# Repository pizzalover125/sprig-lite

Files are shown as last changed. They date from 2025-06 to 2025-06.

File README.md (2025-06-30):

# sprig-lite
A miniature version of the Sprig game console. Featuring the smallest, Arduino-compatible DIP processor and 3 push buttons!

## Images:







## BOM 
NOTE: I am not using AliExpress because they are super unreliable and misdelivered my old package. Fourtanetly, I found it at my neighbor's house. They also just mark it as delivered when it is out for delivery. Also tariffs. 
* 5x EG1218 Slide Switch
* 2x Attiny85 w/ Socket
* 40x 1k Resistors
* 2x i2c 0.96" OLED
* 1x Keystone 2462 Battery Holder
* 1x Arduino Uno R3 (to program the board)
  
 

$57.14 w/ tax + shipping

* 1x Foam Tape
* Misc Screws

$15.00 from Home Depot w/ tax

* 5x JLC PCB ($15.55)
* Breadboard Wires (FREE)
* 3mm LEDs (FREE)
* 6mm Buttons (FREE)

**Total: $87.69**

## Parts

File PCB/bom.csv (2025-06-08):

Designator | Footprint | Quantity | Value | LCSC Part #
BT1 | BatteryHolder_Keystone_2462_2xAA | 1 | Battery
BUTTON1, BUTTON2, BUTTON3 | SW_PUSH_6mm_H4.3mm | 3 | SW_Push
D1 | LED_D3.0mm | 1 | LED
OLED1 | MODULE_DM-OLED096-636 | 1 | DM-OLED096-636
POWERSWITCH1 | SW_EG1218 | 1 | SW_Wuerth_450301014042
R1, R2, R3, R4 | R_Axial_DIN0207_L6.3mm_D2.5mm_P7.62mm_Horizontal | 4 | 1K
U1 | DIP-8_W7.62mm | 1 | ATtiny85

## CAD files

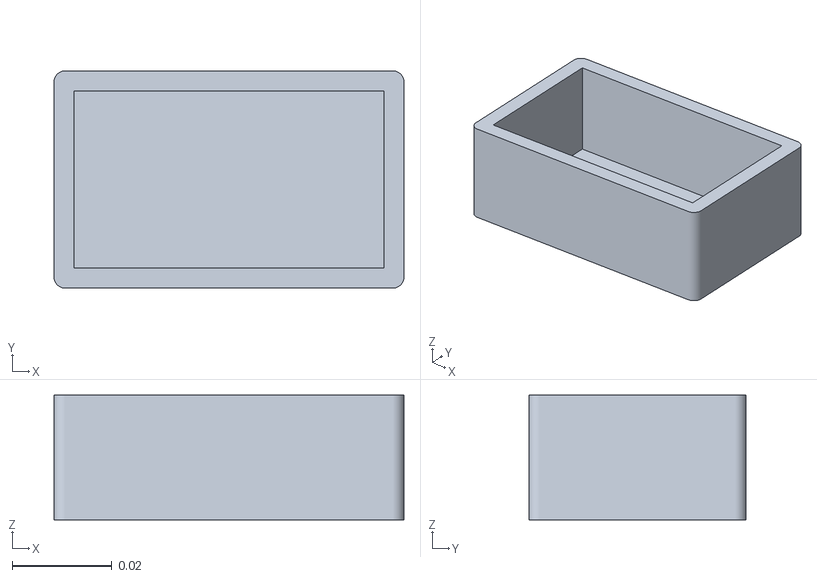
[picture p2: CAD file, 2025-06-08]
CAD/body.stl
0.0701 x 0.0435 x 0.025

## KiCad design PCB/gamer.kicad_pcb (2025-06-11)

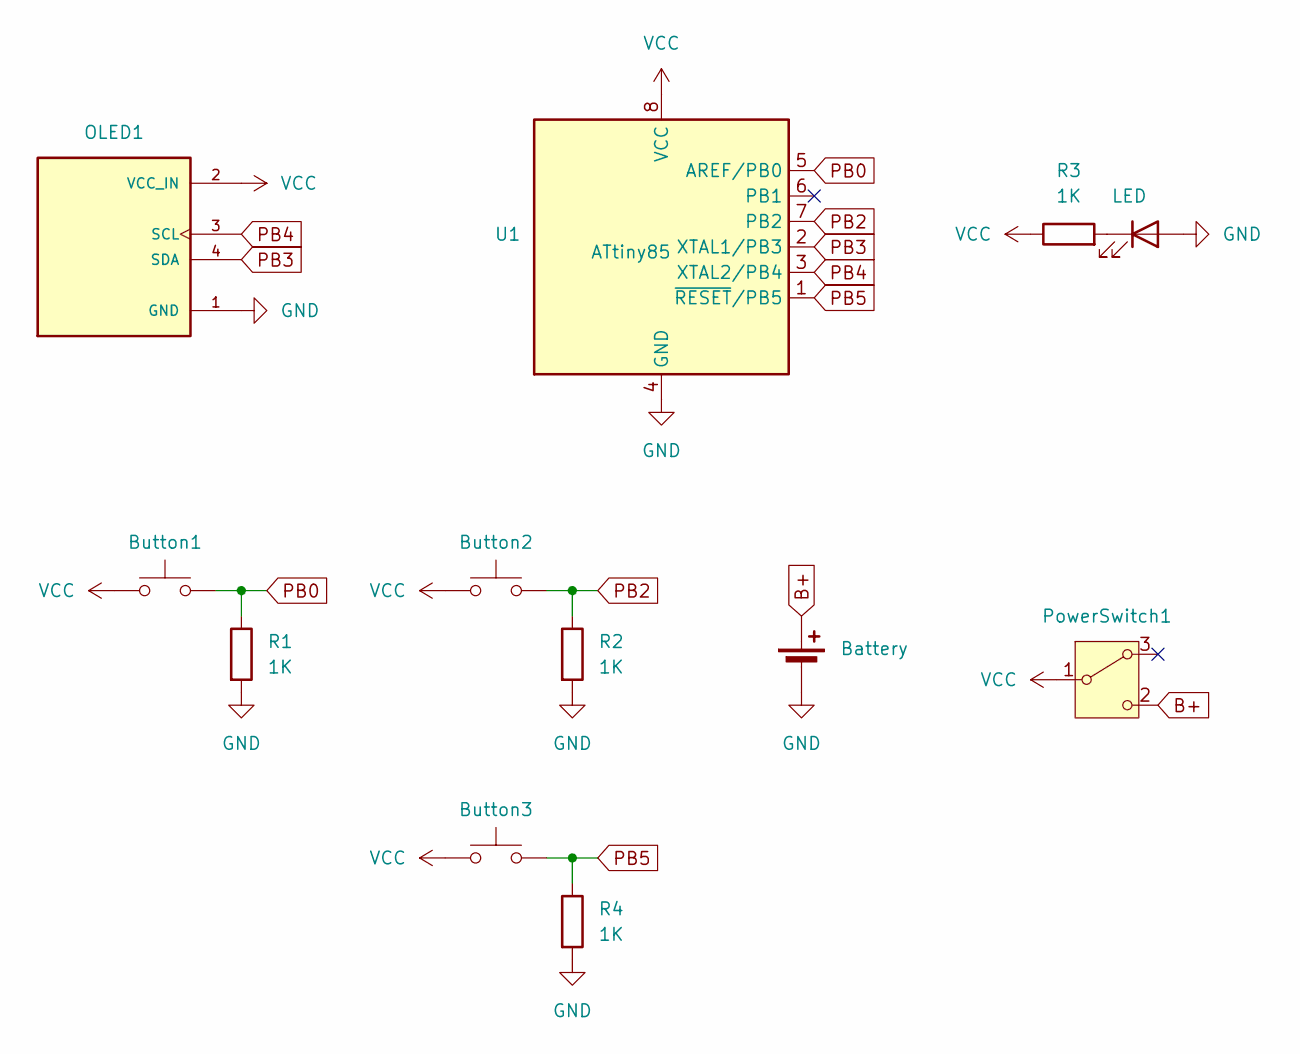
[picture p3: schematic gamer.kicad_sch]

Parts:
BT1: Battery; BatteryHolder_Keystone_2462_2xAA
Button1, Button2, Button3: SW_Push; SW_PUSH_6mm_H4.3mm
D1: LED; LED_D3.0mm
OLED1: DM-OLED096-636; MODULE_DM-OLED096-636; PARTREV 2018-09-10
PowerSwitch1: SW_Wuerth_450301014042; SW_EG1218
R1, R2, R3, R4: 1K; R_Axial_DIN0207_L6.3mm_D2.5mm_P7.62mm_Horizontal
U1: ATtiny85; DIP-8_W7.62mm

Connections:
B+: BT1.1 (+), PowerSwitch1.2 (C)
GND: BT1.2 (-), D1.2 (A), OLED1.1 (GND), R1.2, R2.2, R4.2, U1.4 (GND)
unnamed: D1.1 (K), R3.2
PB0: Button1.2, R1.1, U1.5 (AREF/PB0)
PB2: Button2.2, R2.1, U1.7 (PB2)
PB3: OLED1.4 (SDA), U1.2 (XTAL1/PB3)
PB4: OLED1.3 (SCL), U1.3 (XTAL2/PB4)
PB5: Button3.2, R4.1, U1.1 (~RESET/PB5)
VCC: Button1.1, Button2.1, Button3.1, OLED1.2 (VCC_IN), PowerSwitch1.1 (B), R3.1, U1.8 (VCC)

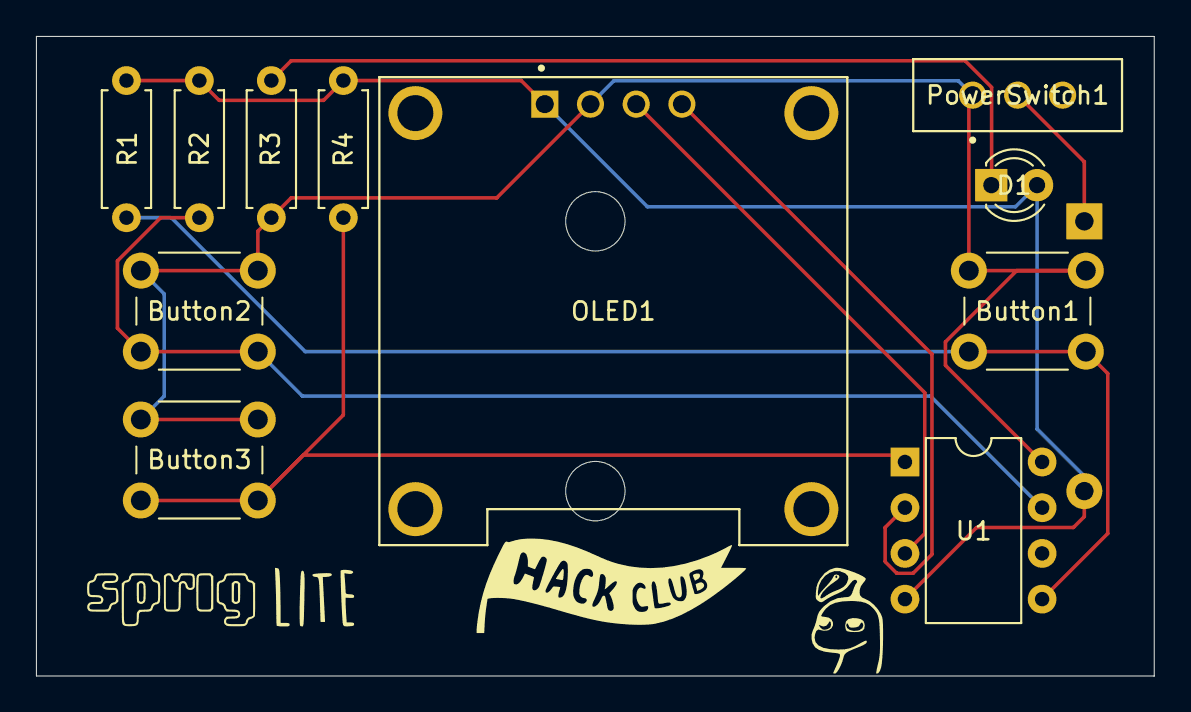
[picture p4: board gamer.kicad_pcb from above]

Board: 2 copper layers, 62.1 x 35.5 mm, 12 parts (1 on the bottom side), 9 nets.

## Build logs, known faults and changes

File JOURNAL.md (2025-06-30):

---
title: "Sprig Lite"
author: "pizzalover125"
description: "A mini game console."
created_at: "2025-06-25"
---
**Time Spent: 12 hours**
### 6/5/25
A couple of years ago, I got introduced to the attiny85 in an electronics class. I basically built this exact project on a breadboard. That was SUPER cool and was where I began my electronics journey. Ok so I began with the PCB. Schematic was super simple, as the attiny85 is super simple. Originally, I was thinking to have a CR2032 for a battery as it is super small and minimalist. Then I realized that I could make a game console fit on the back of 2 AA batteries. I also liked that because it would give me infinite battery life. So I went with that. I then made the PCB layout and routed everything super fast. It was super easy. 


### 6/7/25
Today I made some minor refinements. First, I added PCB silkscreen art. I also decided to call this project "sprig-lite" and use their artowrk and stuff. Then, I decided to add an aditional button for the ability to play more games. For some reason changing the switch was super hard. KiCad just wouldn't work :cry:. Eventually, I got this one model to work. I also calculated that this device will literlly have 60-70 hours of battery life. I also made the BOM. This project, I'll use Amazon because AliExpress is just too unreliable. I also decided to ditch the 3D case because its too pointless for a device supposed to be minimal and I don't want to make it bigger. Here is the finished product: EDIT: I'll include the case and use mounting tape. The reason is that I'll have to offset the PCB from the battery so the solder joints from the top don't hit the batteries. 


### 6/10/25
My project got rejected :( and I was told to make firmware. So... I did! Note that its heavily based off of the projects made in https://electronoobs.com/eng_arduino_tut120_code1.php. But then I realized I don't understand any of the code :(. So... instead of trying to rewrite the binary values, I just changed my schematic and PCB. 

### 6/29/25
I wanted to make this 6 points, so I was told to make a case. I agree, my case looks ABSOLUTELY DISGUSTING. It's literally just a box. So, I decided to add fins on both side so people could hold the console properly. It was pretty simple, but it looked complete with filets all over:


Then, I added a back panel that can be screwed off, so the batteries can be accessed. It used M3 screws btw:


And, we're done!

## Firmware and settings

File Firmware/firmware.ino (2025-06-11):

#include <EEPROM.h>
#include "font6x8AJ.h"
#include <avr/sleep.h>
#include <avr/interrupt.h> // needed for the additional interrupt

#define DIGITAL_WRITE_HIGH(PORT) PORTB |= (1 << PORT)
#define DIGITAL_WRITE_LOW(PORT) PORTB &= ~(1 << PORT)

// Routines to set and clear bits (used in the sleep code)
#define cbi(sfr, bit) (_SFR_BYTE(sfr) &= ~_BV(bit))
#define sbi(sfr, bit) (_SFR_BYTE(sfr) |= _BV(bit))

// Defines for OLED output
#define SSD1306XLED_H
#define SSD1306_SCL   PORTB4  // SCL, Pin 4 on SSD1306 Board - for webbogles board
#define SSD1306_SDA   PORTB3  // SDA, Pin 3 on SSD1306 Board - for webbogles board
#define SSD1306_SA    0x78  // Slave address

// Function prototypes
void resetAliens(void);
void drawPlatform(void);
void sendBlock(int);
void playSpaceAttack(void);
void beep(int,int);
void levelUp(int);
void drawFire(int x, int y);
void doDrawLS(long, byte);
void doDrawRS(long, byte);
void clearAlienArea(int row, int lastActive);
void doNumber (int x, int y, int value);
void ssd1306_init(void);
void ssd1306_xfer_start(void);
void ssd1306_xfer_stop(void);
void ssd1306_send_byte(uint8_t byte);
void ssd1306_send_command(uint8_t command);
void ssd1306_send_data_start(void);
void ssd1306_send_data_stop(void);
void ssd1306_setpos(uint8_t x, uint8_t y);
void ssd1306_fillscreen(uint8_t fill_Data);
void ssd1306_char_f6x8(uint8_t x, uint8_t y, const char ch[]);
void ssd1306_draw_bmp(uint8_t x0, uint8_t y0, uint8_t x1, uint8_t y1, uint8_t bitmap[]);

long firecounter = 0; // Timer for managing fire
long aliencounter = 0; // Timer for alien movement
int mothercounter = 0; // Timer for movement of the mothership
int level = 1; // Game level - incremented every time you clear the screen
int mothershipX = 0; // position of mothership
int mothership = 0; // is mothership active?
int mothershipWidth = 8; // mothership width in pixels
int fireXidx, fireYidx; // mapping of player fire locaiton onto array of aliens
int leftLimit; // furtherst left in x-axis pixels that the aliens are currently
int positionNow = 0; // current position of the alien array (as steps from the left)
boolean alienDirection = 1; // current direction of travel for alien swarm - 1 is right 0 is left
int alienRow = 0; // which alien row are we considering
int alienFire[5][3]; // max 5 lots of alien fire  - indices are active, xpos, ypos
int playerFire[3]; // one lot of player fire - indices are active, xpos, ypos
boolean row[4][10]; // on-off array of aliens
int firstAlien = 0; // index of first live alien in the array
int lastAlien = 8; // index of last live alien in the array
int newFirst = firstAlien; // as above when it changes
int newLast = lastAlien; // ...
int aliensDead = 0; // how many aliens have been killed in total on this level?
int lastActiveRow = 2; // what's the lowest row in which we will find live aliens?
int deadOn1 = 0; // how many aliens are dead on row one (middle row)
int deadOn2 = 0; // how many aliens are dead on row two (bottom row)

boolean fire = 0;
int topScoreB = 0;
int player; //0 to 128-platformWidth  - this is the position of the player
int platformWidth = 16; 
boolean stopAnimate = 0; // this is set to 1 when a collision is detected
boolean mute = 0;
boolean newHigh = 0;
int score = 0; // score - this affects the difficulty of the game
int top = 0;

// Interrupt handlers
ISR(PCINT0_vect){ // PB0 pin button interrupt           
   if (digitalRead(2)==1) fire = 1;
}

void playerIncSpaceAttack(){ // PB2 pin button interrupt
  if (digitalRead(0)==1) fire = 1;
}

// Arduino stuff - setup
void setup() {
  DDRB = 0b00000010;    // set PB1 as output (for the speaker)
  PCMSK = 0b00000001; // pin change mask: listen to portb bit 1
  GIMSK |= 0b00100000;  // enable PCINT interrupt 
  sei();          // enable all interrupts
}

// Arduino stuff - loop
void loop() { 
  ssd1306_init();
  ssd1306_fillscreen(0x00);
  
  // The lower case character set is seriously compromised because I've had to truncate the ASCII table
  // to release space for executable code - hence lower case y and w are remapped to h and / respectively.
  // There is no z in the table (or h!) as these aren't used anywhere in the text here and most of the 
  // symbols are also missing for the same reason (see my hacked version of font6x8.h - font6x8AJ.h for more detail)
  ssd1306_char_f6x8(0, 1, "S P A C E");
  ssd1306_char_f6x8(4, 2, "A T T A C K");
  ssd1306_char_f6x8(0, 4, "andh jackson"); // see comments above !

  ssd1306_setpos(85,1);
  ssd1306_send_data_start();
  sendBlock(1);
  sendBlock(0);  
  sendBlock(1);
  ssd1306_send_data_stop();
  ssd1306_setpos(85,2);
  ssd1306_send_data_start();
  sendBlock(0);
  sendBlock(2);
  sendBlock(0);
  ssd1306_send_data_stop();
  ssd1306_setpos(85,3);
  ssd1306_send_data_start();
  sendBlock(0);
  sendBlock(0);  
  sendBlock(1);
  sendBlock(0);  
  sendBlock(1);
  ssd1306_send_data_stop();
  player = 96;
  drawPlatform();

  long startT = millis();
  long nowT =0;
  boolean sChange = 0;
  while(digitalRead(0) == HIGH) {
    nowT = millis();
    if (nowT - startT > 2000) {
      sChange = 1;     
      if (digitalRead(2) == HIGH) {
        EEPROM.write(0,0);
        EEPROM.write(1,0);
        ssd1306_char_f6x8(8, 0, "-HIGH SCORE RESET-");  
      } else if (mute == 0) { mute = 1; ssd1306_char_f6x8(32, 0, "-- MUTE --"); } else { mute = 0; ssd1306_char_f6x8(23, 0, "-- SOUND ON --");  }    
      break;
    }
    if (sChange == 1) break;
  }  
  while(digitalRead(0) == HIGH);


  if (sChange == 0) {
    for (byte mm = 112;mm>=1;mm--) {
      if ( (mm>=32) && (mm<56) ) drawFire(104,mm);
      if (mm == 32) {
        ssd1306_setpos(100,3);      
        ssd1306_send_data_start();
        sendBlock(0);
        ssd1306_send_data_stop();
        ssd1306_setpos(100,4);      
        ssd1306_send_data_start();
        sendBlock(0);
        ssd1306_send_data_stop();
        beep(30,100);
      }
      ssd1306_setpos(mm,0);      
      ssd1306_send_data_start();
      sendBlock(3);
      sendBlock(0);
      ssd1306_send_data_stop();
      drawPlatform();
      delay(20);
    }
    ssd1306_setpos(0,0);      
    ssd1306_send_data_start();
    sendBlock(0);
    sendBlock(0);
    ssd1306_send_data_stop();
    ssd1306_char_f6x8(0, 6, "inspired bh");  // see comments above !
    ssd1306_char_f6x8(0, 7, "/ebboggles.com");  // see comments above !
    delay(1500);
    ssd1306_init();
    ssd1306_fillscreen(0x00);
    stopAnimate = 0;
    score = 0;

    playSpaceAttack(); 
    top=topScoreB;
    
    ssd1306_fillscreen(0x00);
    ssd1306_char_f6x8(11, 1, "----------------");
    ssd1306_char_f6x8(11, 2, "G A M E  O V E R");
    ssd1306_char_f6x8(11, 3, "----------------");
    ssd1306_char_f6x8(37, 5, "SCORE:");
    doNumber(75, 5, score);
    if (!newHigh) {
      ssd1306_char_f6x8(21, 7, "HIGH SCORE:");
      doNumber(88, 7, top);
    }
    for (int i = 0; i<1000; i = i+ 50){
      beep(50,i);
    }
    delay(2000);
    if (newHigh) {
      ssd1306_fillscreen(0x00);
      ssd1306_char_f6x8(10, 1, "----------------");
      ssd1306_char_f6x8(10, 3, " NEW HIGH SCORE ");
      ssd1306_char_f6x8(10, 7, "----------------");
      doNumber(50,5,top);
      for (int i = 700; i>200; i = i - 50){
      beep(30,i);
      }
      newHigh = 0;
      delay(2700);    
    } 
  }
  system_sleep();
}

void doNumber (int x, int y, int value) {
    char temp[10] = {0,0,0,0,0,0,0,0,0,0};
    itoa(value,temp,10);
    ssd1306_char_f6x8(x, y, temp);
}

void ssd1306_init(void){
  DDRB |= (1 << SSD1306_SDA); // Set port as output
  DDRB |= (1 << SSD1306_SCL); // Set port as output

  ssd1306_send_command(0xAE); // display off
  ssd1306_send_command(0x00); // Set Memory Addressing Mode
  ssd1306_send_command(0x10); // 00,Horizontal Addressing Mode;01,Vertical Addressing Mode;10,Page Addressing Mode (RESET);11,Invalid
  ssd1306_send_command(0x40); // Set Page Start Address for Page Addressing Mode,0-7
  ssd1306_send_command(0x81); // Set COM Output Scan Direction
  ssd1306_send_command(0xCF); // ---set low column address
  ssd1306_send_command(0xA1); // ---set high column address
  ssd1306_send_command(0xC8); // --set start line address
  ssd1306_send_command(0xA6); // --set contrast control register
  ssd1306_send_command(0xA8);
  ssd1306_send_command(0x3F); // --set segment re-map 0 to 127
  ssd1306_send_command(0xD3); // --set normal display
  ssd1306_send_command(0x00); // --set multiplex ratio(1 to 64)
  ssd1306_send_command(0xD5); // 
  ssd1306_send_command(0x80); // 0xa4,Output follows RAM content;0xa5,Output ignores RAM content
  ssd1306_send_command(0xD9); // -set display offset
  ssd1306_send_command(0xF1); // -not offset
  ssd1306_send_command(0xDA); // --set display clock divide ratio/oscillator frequency
  ssd1306_send_command(0x12); // --set divide ratio
  ssd1306_send_command(0xDB); // --set pre-charge period
  ssd1306_send_command(0x40); // 
  ssd1306_send_command(0x20); // --set com pins hardware configuration
  ssd1306_send_command(0x02);
  ssd1306_send_command(0x8D); // --set vcomh
  ssd1306_send_command(0x14); // 0x20,0.77xVcc
  ssd1306_send_command(0xA4); // --set DC-DC enable
  ssd1306_send_command(0xA6); // 
  ssd1306_send_command(0xAF); // --turn on oled panel 
}

void ssd1306_xfer_start(void){
  DIGITAL_WRITE_HIGH(SSD1306_SCL);  // Set to HIGH
  DIGITAL_WRITE_HIGH(SSD1306_SDA);  // Set to HIGH
  DIGITAL_WRITE_LOW(SSD1306_SDA);   // Set to LOW
  DIGITAL_WRITE_LOW(SSD1306_SCL);   // Set to LOW
}

void ssd1306_xfer_stop(void){
  DIGITAL_WRITE_LOW(SSD1306_SCL);   // Set to LOW
  DIGITAL_WRITE_LOW(SSD1306_SDA);   // Set to LOW
  DIGITAL_WRITE_HIGH(SSD1306_SCL);  // Set to HIGH
  DIGITAL_WRITE_HIGH(SSD1306_SDA);  // Set to HIGH
}

void ssd1306_send_byte(uint8_t byte){
  uint8_t i;
  for(i=0; i<8; i++)
  {
    if((byte << i) & 0x80)
      DIGITAL_WRITE_HIGH(SSD1306_SDA);
    else
      DIGITAL_WRITE_LOW(SSD1306_SDA);
    
    DIGITAL_WRITE_HIGH(SSD1306_SCL);
    DIGITAL_WRITE_LOW(SSD1306_SCL);
  }
  DIGITAL_WRITE_HIGH(SSD1306_SDA);
  DIGITAL_WRITE_HIGH(SSD1306_SCL);
  DIGITAL_WRITE_LOW(SSD1306_SCL);
}

void ssd1306_send_command(uint8_t command){
  ssd1306_xfer_start();
  ssd1306_send_byte(SSD1306_SA);  // Slave address, SA0=0
  ssd1306_send_byte(0x00);  // write command
  ssd1306_send_byte(command);
  ssd1306_xfer_stop();
}

void ssd1306_send_data_start(void){
  ssd1306_xfer_start();
  ssd1306_send_byte(SSD1306_SA);
  ssd1306_send_byte(0x40);  //write data
}

void ssd1306_send_data_stop(void){
  ssd1306_xfer_stop();
}

void ssd1306_setpos(uint8_t x, uint8_t y)
{
  if (y>7) return;
  ssd1306_xfer_start();
  ssd1306_send_byte(SSD1306_SA);  //Slave address,SA0=0
  ssd1306_send_byte(0x00);  //write command

  ssd1306_send_byte(0xb0+y);
  ssd1306_send_byte(((x&0xf0)>>4)|0x10); // |0x10
  ssd1306_send_byte((x&0x0f)|0x01); // |0x01

  ssd1306_xfer_stop();
}

void ssd1306_fillscreen(uint8_t fill_Data){
  uint8_t m,n;
  for(m=0;m<8;m++)
  {
    ssd1306_send_command(0xb0+m); //page0-page1
    ssd1306_send_command(0x00);   //low column start address
    ssd1306_send_command(0x10);   //high column start address
    ssd1306_send_data_start();
    for(n=0;n<128;n++)
    {
      ssd1306_send_byte(fill_Data);
    }
    ssd1306_send_data_stop();
  }
}

void ssd1306_char_f6x8(uint8_t x, uint8_t y, const char ch[]){
  uint8_t c,i,j=0;
  while(ch[j] != '\0')
  {
    c = ch[j] - 32;
    if (c >0) c = c - 12;
    if (c >15) c = c - 6;
    if (c>40) c=c-9;
    if(x>126)
    {
      x=0;
      y++;
    }
    ssd1306_setpos(x,y);
    ssd1306_send_data_start();
    for(i=0;i<6;i++)
    {
      ssd1306_send_byte(pgm_read_byte(&ssd1306xled_font6x8[c*6+i]));
    }
    ssd1306_send_data_stop();
    x += 6;
    j++;
  }
}

void system_sleep() {
  ssd1306_fillscreen(0x00);
  ssd1306_send_command(0xAE);
  cbi(ADCSRA,ADEN);                    // switch Analog to Digitalconverter OFF
  set_sleep_mode(SLEEP_MODE_PWR_DOWN); // sleep mode is set here
  sleep_enable();
  sleep_mode();                        // System actually sleeps here
  sleep_disable();                     // System continues execution here when watchdog timed out 
  sbi(ADCSRA,ADEN);                    // switch Analog to Digitalconverter ON  
  ssd1306_send_command(0xAF);
}

void beep(int bCount,int bDelay){
  if (mute) return;
  for (int i = 0; i<=bCount; i++){digitalWrite(1,HIGH);for(int i2=0; i2<bDelay; i2++){__asm__("nop\n\t");}digitalWrite(1,LOW);for(int i2=0; i2<bDelay; i2++){__asm__("nop\n\t");}}
}



/* ------------------------
 *  SpaceAttack Code
 */
void playSpaceAttack() {

  firecounter = 0; // Timer for managing fire
  level = 1; // Game level - incremented every time you clear the screen
  topScoreB = 0; // highscore
  score = 0; // obvious
  
  // Initialisations
  for (byte i = 0; i<5;i++) {
    alienFire[i][0] = 0;
  }
  resetAliens();

  levelUp(1); // This also does various essential initialisations
  
  attachInterrupt(0,playerIncSpaceAttack,CHANGE);

  while (stopAnimate == 0) {
    while(1) {
    aliencounter++;
    firecounter++;
    mothercounter++;
    
    // deal with inputs
    if(analogRead(0) < 940) fire =1; // this reads the reset pin (pin 1) of the Attiny85 - to use it, see comments section above

    if(digitalRead(2)==1) {
      if (digitalRead(0)==1) fire = 1;
      if(player < 127-platformWidth) {
        player++;
        } 
    }
    if (digitalRead(0)==1){
      if (digitalRead(2)==1) fire = 1;
      if (player >1){
        player--;
        } 
     }

    if ( (mothership == 0) && (random(0,1000) > 998) && (alienRow>0) ) {
      mothership = 1;
      mothershipX= 127-16;
    }

    // draw aliens
    for (int inc = 0; inc <= lastActiveRow; inc ++) {
      ssd1306_setpos((positionNow*8),inc+alienRow);
      ssd1306_send_data_start();
      for (int bl = firstAlien; bl <=lastAlien; bl++){
        if(row[inc][bl]==1){
          if (inc == lastActiveRow) {
            if(random(0,1000) > (999-level)) { // this alien is going to fire!
              byte afIndex = 0;
              while (alienFire[afIndex][0] == 1) {
                afIndex++; // search for empty alien fire option
                if (afIndex == 5) break;
              } 
              if (afIndex < 5) { // we've found a slot
                alienFire[afIndex][0] = 1; // activate fire on this slot
                alienFire[afIndex][1] = ( (positionNow*8) + ((bl-firstAlien) * 8) + 4); // x position
                alienFire[afIndex][2] = (inc+alienRow+1)*8; // Where the fire starts
              }
            } // end of this alien firing
          } // only if we are on the lowest row of live aliens
          if ( (inc == 0) || (inc == 2) ) {
            sendBlock(1);
          } else {
            sendBlock(2);
          }
        }else {
          sendBlock(0);
        }
       }   
      ssd1306_send_data_stop();
    }


    // Display the score
    doNumber(0,6,score);
    
    // Burn clock cycles to keep game at constant (ish) speed when there are low numbers of live aliens 
    int burnLimit = (8-(lastAlien-firstAlien));
    for (int burn = 0; burn < burnLimit; burn+=2) {                  
        drawPlatform();    
        }

    // Display the mothership
    if (mothercounter >= 3) {
      mothercounter = 0;    
      // draw mothership
      if (mothership) {
        ssd1306_setpos(mothershipX,0);
        ssd1306_send_data_start();
        sendBlock(3);
        sendBlock(0);
        ssd1306_send_data_stop();
        mothershipX --;
        if (mothershipX == 0) {
          mothership = 0;                      
          ssd1306_setpos(mothershipX,0);
          ssd1306_send_data_start();
          sendBlock(0);
          sendBlock(0);
          ssd1306_send_data_stop();
        }
      }
    }

    // Move the aliens
    if (aliencounter >= (92-((level-1)*5)) ) {
        aliencounter = 0;
      if(alienDirection) { // Moving right
        // move down a row
        if (positionNow >= 6+(8-(lastAlien-firstAlien))) {
          alienDirection = 0;
          clearAlienArea(alienRow,lastActiveRow);                                   
          alienRow++;
        } else {
          positionNow++;
        }
      } else { // Moving left
        // move down a row
        if (positionNow <= 0) {
          alienDirection = 1;
          clearAlienArea(alienRow,lastActiveRow);                                   
          alienRow++;
        } else {
          positionNow --;
        }
      } 
      clearAlienArea(alienRow,lastActiveRow);                                   
    }

    // Fire !
    if ((fire == 1) && (playerFire[0] == 0)) { // fire has been pressed and we're not currently firing - initiate fire!!
      playerFire[0] = 1;
      playerFire[1] = player+platformWidth/2; // xposition of new fire!
      playerFire[2] = 56;
    }

    // Handle all firing-related stuff (in both directions!)
    if (firecounter >= 2) {                  
      firecounter = 0;
      // --- Deal with player Firing --- 
      if (playerFire[0] == 1) {                      
          drawFire(playerFire[1], playerFire[2]);
          if (playerFire[2] == 0) {
            ssd1306_setpos(playerFire[1],0);
            uint8_t temp = B00000000;
            ssd1306_send_data_start();
            ssd1306_send_byte(temp);  
            ssd1306_send_data_stop();                                                          
            playerFire[0] = 0;
            fire = 0;
          } else {
            playerFire[2] = playerFire[2] - 1;                          
          }
      }
      
      // aliens are at positionNow * 8 + 8* their index
      
      leftLimit = positionNow*8;
      if ((fire == 1)) {
        fireXidx = firstAlien + floor((playerFire[1]-positionNow*8)/8);                    
        fireYidx=  floor(floor(playerFire[2]/8) - alienRow);
        
        if((mothership == 1) && (playerFire[1] >= mothershipX) && (playerFire[1] <= mothershipX +8) && playerFire[2] <=8) {
          long scm = random(1,100);
          if (scm<30) {
            score +=50;
          } else if (scm<60) {
            score += 100;
          } else if (scm<90) {
            score += 150;
          } else {
            score += 300;
          }
            
          beep(30,400);
          beep(30,300);          
          beep(30,200);
          beep(30,100);
          mothership = 0;
          ssd1306_setpos(mothershipX,0);
          ssd1306_send_data_start();
          sendBlock(0);
          sendBlock(0);
          ssd1306_send_data_stop();
        }

        // Alien has been hit
        if ((playerFire[1] >= leftLimit) && (fireYidx>=0) && (fireYidx<=lastActiveRow) && (fireXidx>=0) && (fireXidx<9)) {                    
          if (row[fireYidx][fireXidx] == 1) { 

            int lastActiveToClear = lastActiveRow; // if we kill the last alien on a row - we still need to clear that row (end of this fn)
            
            if (fireYidx == 2) deadOn2++;
            if (fireYidx == 1) deadOn1++;
            
            if (deadOn2 == 5) {lastActiveRow = 1;}
            if ((deadOn1 == 4) && (deadOn2 == 5)) {lastActiveRow = 0;}

            score = score + (int)((3-fireYidx) * 10);
                        
            aliensDead++;                      
            ssd1306_setpos(playerFire[1],alienRow+fireYidx+1);
            uint8_t temp = B00000000;
            ssd1306_send_data_start();
            ssd1306_send_byte(temp);  
            ssd1306_send_data_stop();                                                          
            beep(30,100);
            
            fire = 0;
            playerFire[0] = 0;
            playerFire[1] = 0;
            playerFire[2] = 7;
            row[fireYidx][fireXidx] = 0;
            
            if (fireXidx == firstAlien) { // this is the first Alien - sweep back and reset to new first alien
              for (int xi = lastAlien; xi>=firstAlien;xi--) {
                if ( (row[0][xi] == 1) || (row[1][xi] == 1) || (row[2][xi] == 1) ) newFirst = xi;
              }
              positionNow += newFirst - firstAlien;
              firstAlien = newFirst;
            }
            
            if (fireXidx == lastAlien) { // this is the last Alien - sweep thru and reset to new last alien
              for (int xi = firstAlien; xi<=lastAlien;xi++) {
                if ( (row[0][xi] == 1) || (row[1][xi] == 1) || (row[2][xi] == 1) ) newLast = xi;
              }
              lastAlien = newLast;
            }
            clearAlienArea(alienRow,lastActiveToClear);
                                               
          }         
        }
      }


      // --- Deal with Alien Firing --- 
      for (byte afIndex = 0; afIndex<5; afIndex++) {
        if(alienFire[afIndex][0] == 1) {
          drawFire(alienFire[afIndex][1],alienFire[afIndex][2]);
          alienFire[afIndex][2] = alienFire[afIndex][2] + 1;

          if (alienFire[afIndex][2] >= 56) {
            ssd1306_setpos(alienFire[afIndex][1],7);
            uint8_t temp = B00000000;
            ssd1306_send_data_start();
            ssd1306_send_byte(temp);  
            ssd1306_send_data_stop();                                                          
            alienFire[afIndex][0] = 0; // the fire's got to the end
            if( ((alienFire[afIndex][1]) > player) && ( (alienFire[afIndex][1]) < player+platformWidth) ) { // you've been hit!!
              stopAnimate = 1;
              goto die;
              }
          }
        }                  
      } // end of aliens firing                  
    }

    if (aliensDead == 14) {
      for (int ai = 0; ai <= 5; ai++) alienFire[ai][0] = 0;

      level++;
      if (level>15) level = 15;
      levelUp(level);

      resetAliens();
    }
    
    if( ((alienRow == 5) && (lastActiveRow == 2))||  ( (alienRow == 6) && (lastActiveRow == 1)) || ((alienRow == 7) && (lastActiveRow == 0)) || stopAnimate) {
      stopAnimate = 1;
      break;
    }
    // draw the player
    drawPlatform();
    }
 }
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
